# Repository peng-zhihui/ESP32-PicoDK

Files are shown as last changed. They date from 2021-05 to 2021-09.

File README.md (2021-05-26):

# 基于ESP32-PicoD4的开源迷你开发板
最近芯片疯狂涨价，ST系列的MCU价格已经上天，所以后面打算以ESP32为项目的主力平台。

> 实际上ESP32性能比STM32还强不少：
>
> * 双核架构，主频还高
> * 带WiFi/蓝牙能力（SiP封装内带射频匹配电路）
> * 原生基于FreeRTOS
> * 直接兼容Arduino生态
> * GPIO-Matrix（神器，GPIO互换，PCB Layout友好度拉满）
> * 接口丰富（3个UART、2个I2C、2个SPI、**居然还带CAN**）
> * SiP封装，外围电路极其简洁

最重要的，在芯片价格涨麻了的今天，ESP32只要十多元一片，好家伙我直接推爆好吗。

同时为了方便以后做原型验证，需要用有一个评估板，看了一圈市面上并没有很满意的（连TypeC的都没几个），所以花了一下午自己设计了一个，也开源给大家。

**板子设计已打样验证无误，好用记得点星星**👇

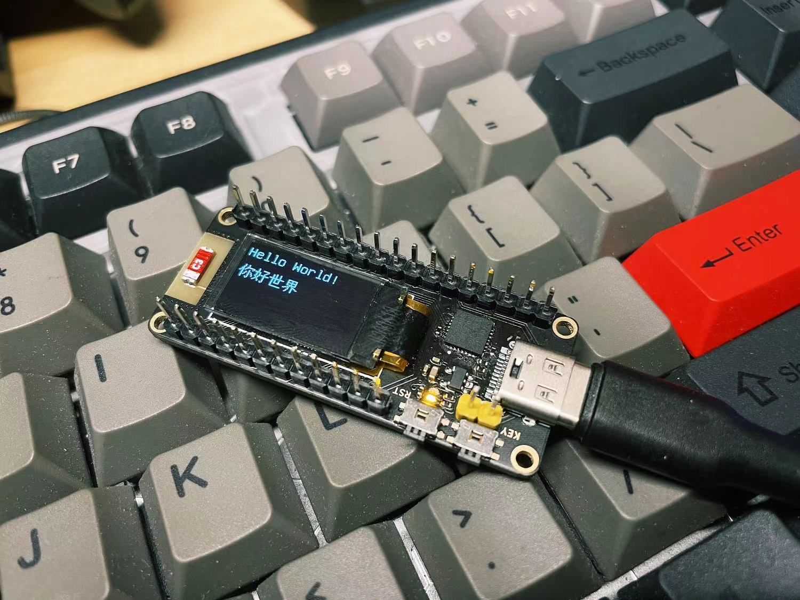
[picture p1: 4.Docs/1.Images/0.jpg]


##  特性

* 所有GPIO引出
* 板载一个MPU6050、一个OLED、一个CAN-PHY芯片、一个USB转串口、一个用户LED、一个用户按键
* 上面提到的外设芯片都是可以在板子背面通过**跳线**选择连接GPIO或者断开的，所以不影响GPIO作其他用途
* 极致迷你尺寸
* 带配套亚克力外壳（设计中稍后更新）

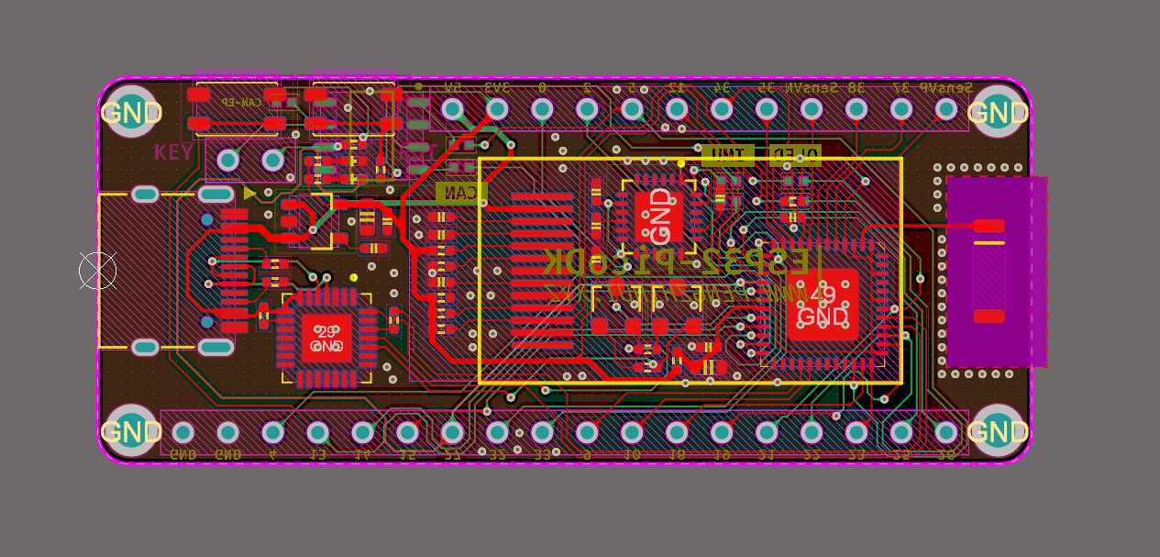
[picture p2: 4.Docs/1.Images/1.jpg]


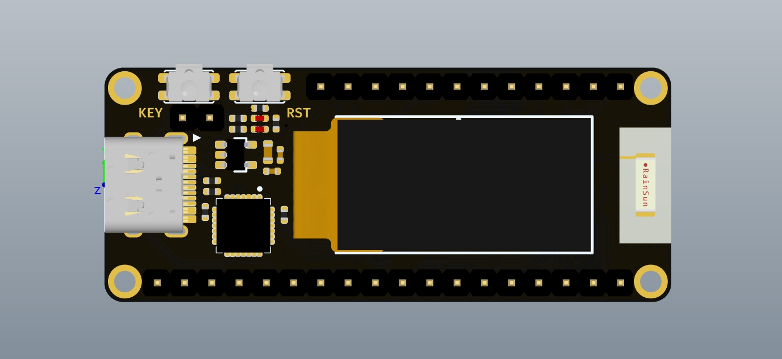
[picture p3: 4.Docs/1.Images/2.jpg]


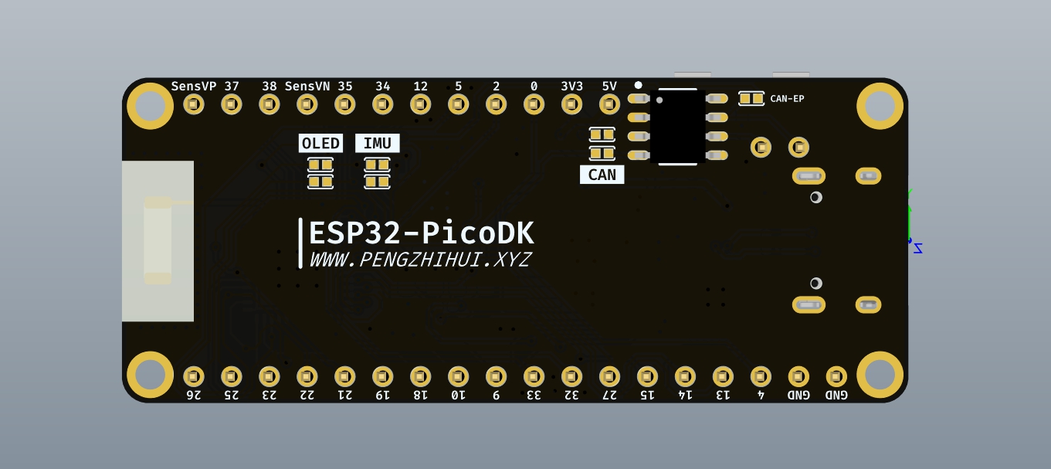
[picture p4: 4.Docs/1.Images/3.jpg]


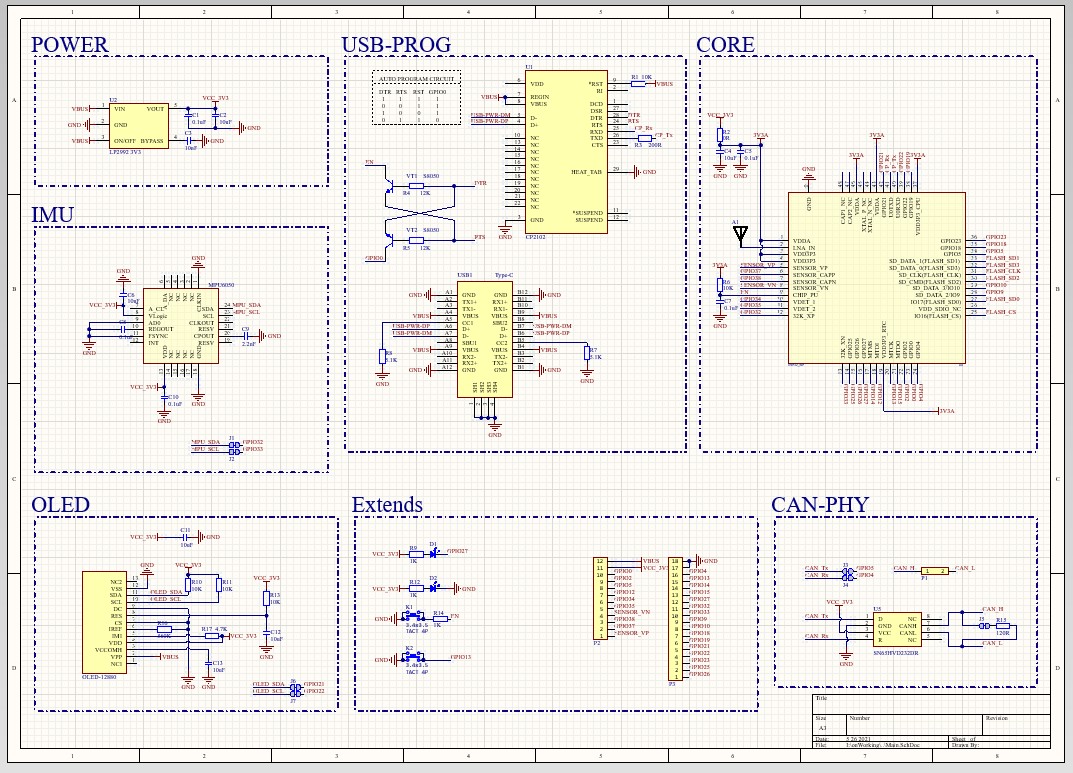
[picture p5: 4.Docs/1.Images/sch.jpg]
sch


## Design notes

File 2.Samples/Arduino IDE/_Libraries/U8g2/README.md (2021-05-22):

# U8g2_Arduino: Arduino Monochrome Graphics Library

https://raw.githubusercontent.com/wiki/olikraus/u8g2/img/uc1701_dogs102_uno_board_320.jpg 

U8glib V2 library for Arduino

Description: https://github.com/olikraus/u8g2/wiki

Issue Tracker: https://github.com/olikraus/u8g2/issues

Download (2.25.10): https://github.com/olikraus/U8g2_Arduino/archive/master.zip

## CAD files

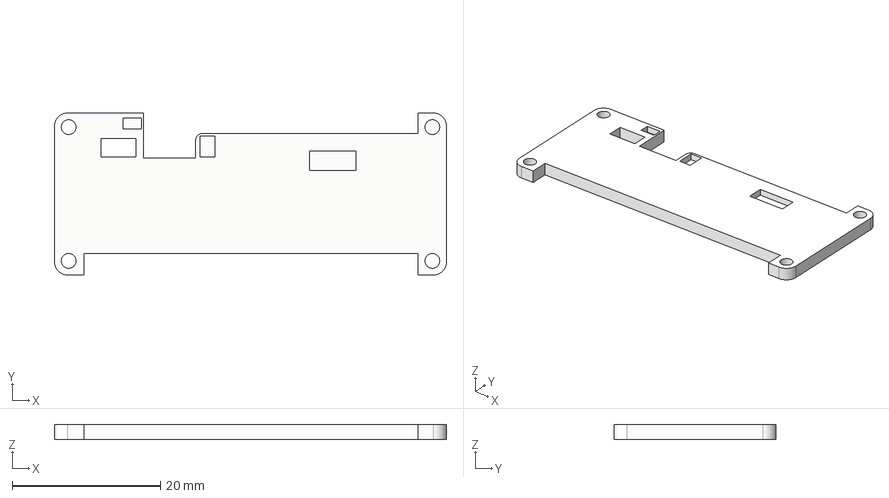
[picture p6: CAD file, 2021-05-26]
3.Case/lower.step
52.8 x 21.8 x 2.00 mm

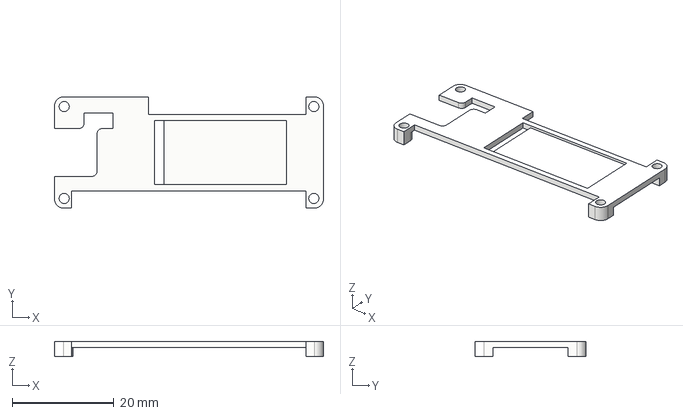
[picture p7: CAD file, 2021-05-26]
3.Case/upper.step
52.8 x 21.8 x 3.00 mm

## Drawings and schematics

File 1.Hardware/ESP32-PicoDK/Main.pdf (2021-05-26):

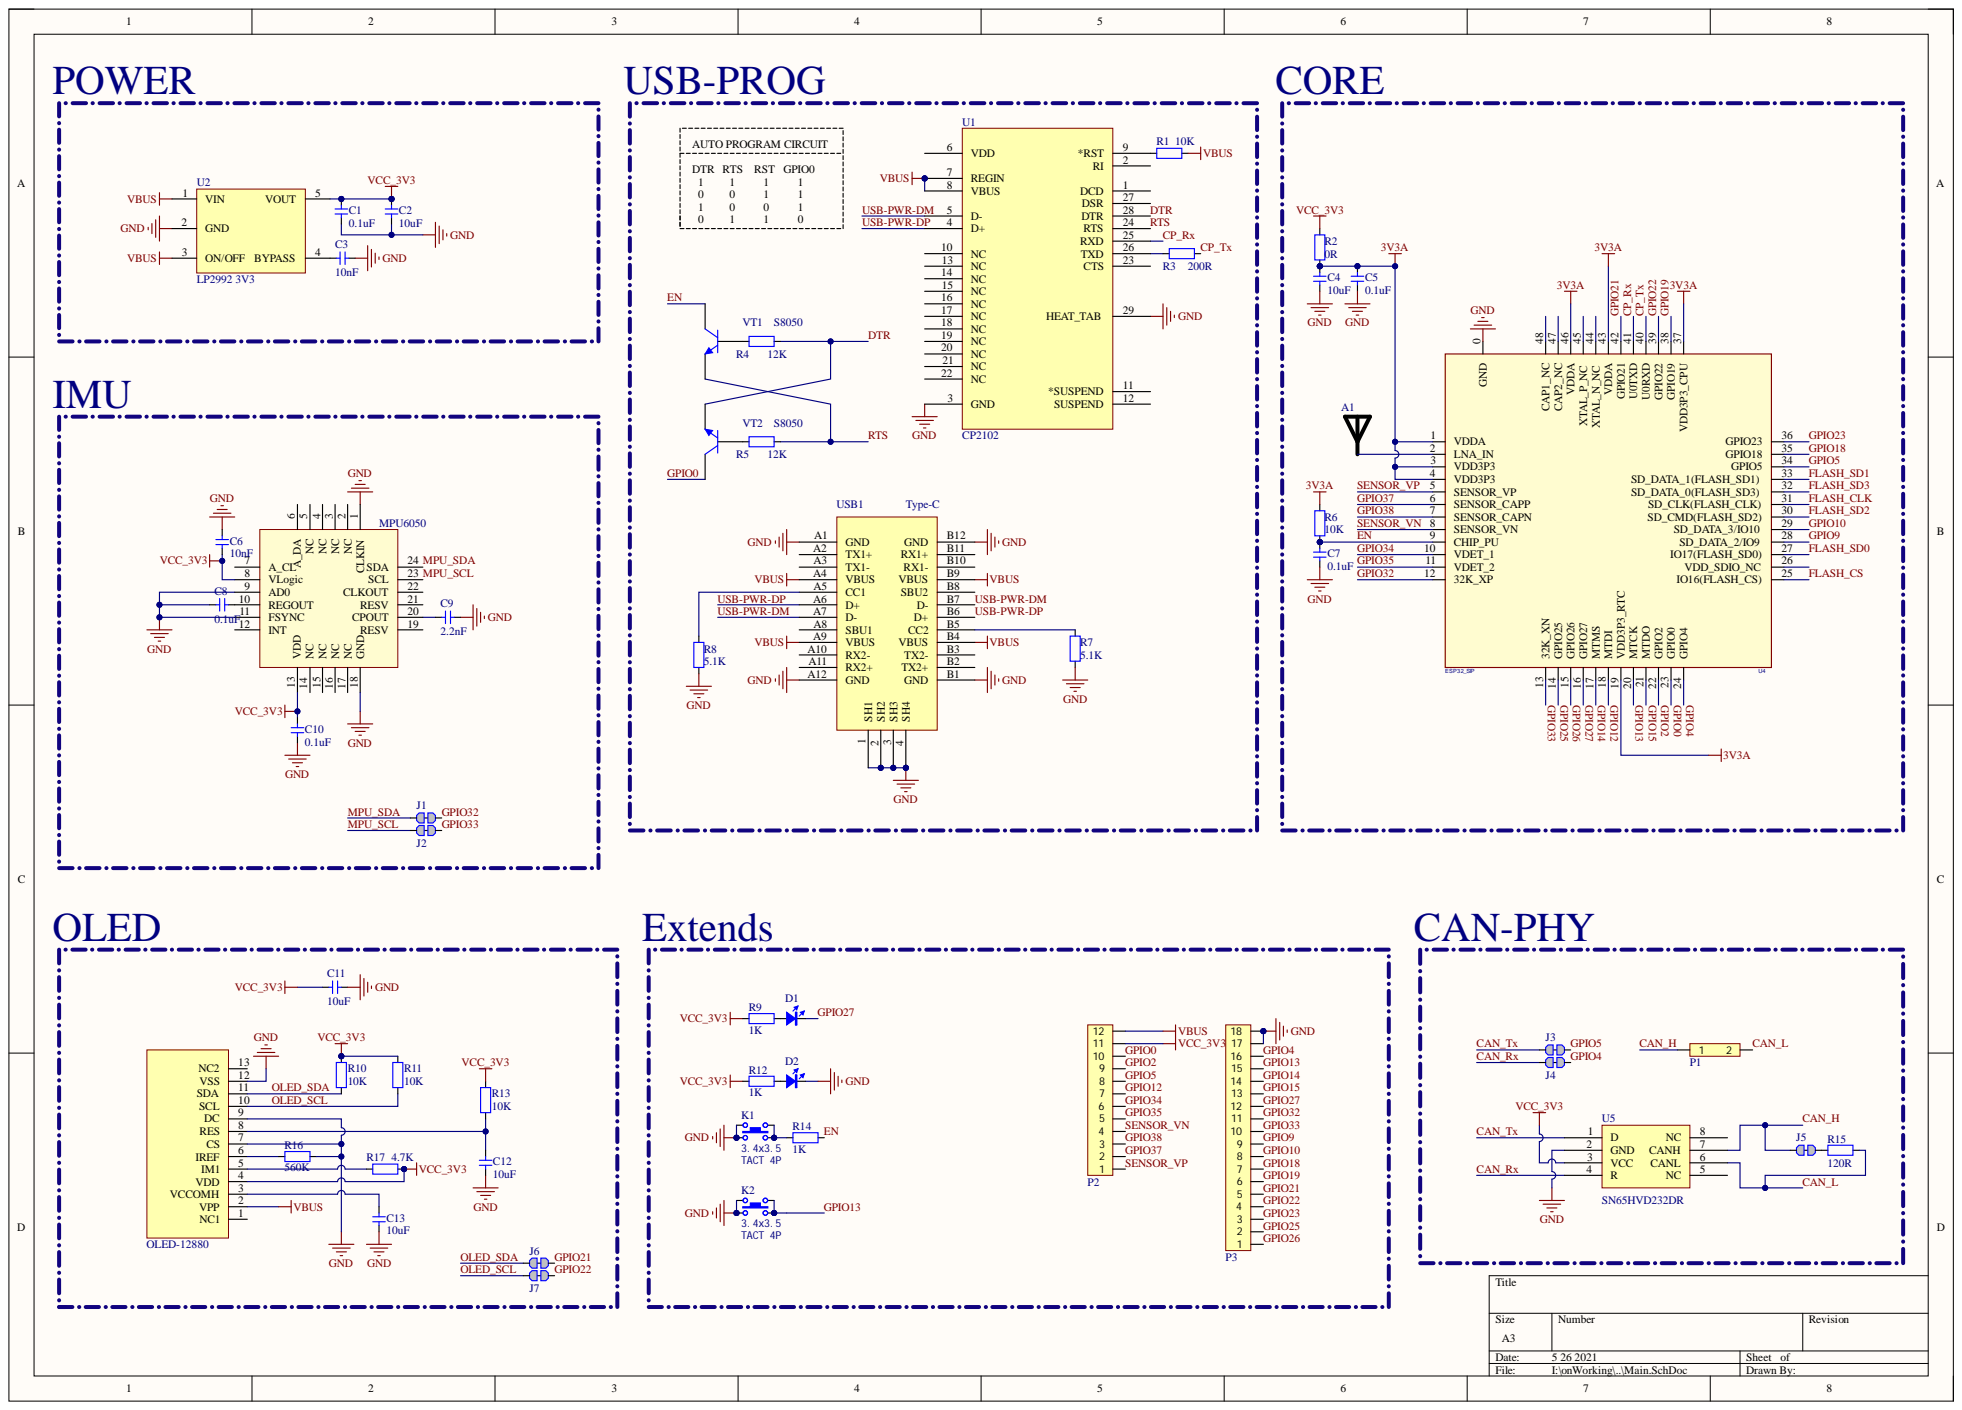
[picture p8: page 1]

CLKIN 1 NC 2 NC 3 NC 4 NC 5 A_DA 6

GND 18 RESV 19 CPOUT 20 RESV 21 CLKOUT 22 SCL 23 SDA 24

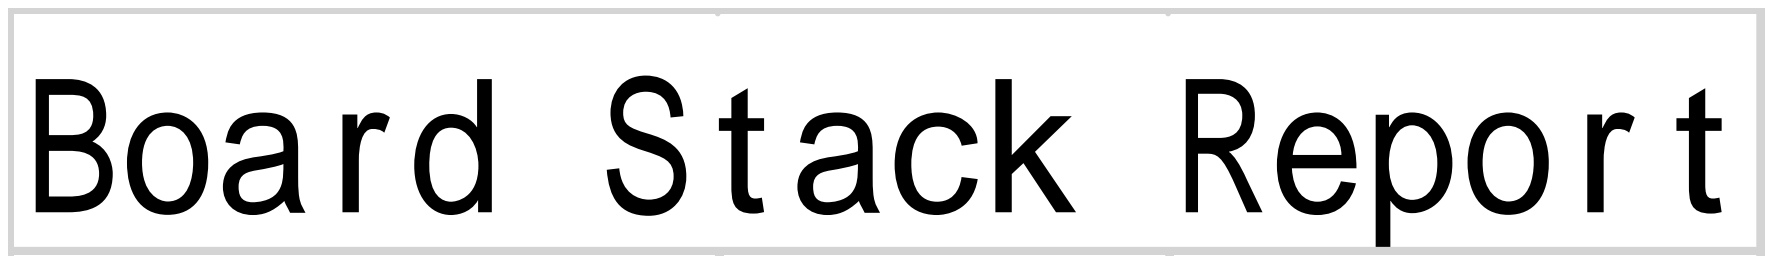
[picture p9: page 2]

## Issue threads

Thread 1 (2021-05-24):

天线部分不做阻抗匹配的话，不知道wifi性能影响大吗

Ncerzzk, 2021-05-24:
rt

peng-zhihui, 2021-05-24:
pico d4的sip封装内是带射频匹配电路的，以前的仓库里已经说明过了

发自我的iPhone

------------------ 原始邮件 ------------------
发件人: Ncerzzk ***@***.***&gt;
发送时间: 2021年5月24日 16:32
收件人: peng-zhihui/ESP32-PicoDK ***@***.***&gt;
抄送: Subscribed ***@***.***&gt;
主题: 回复：[peng-zhihui/ESP32-PicoDK] 天线部分不做阻抗匹配的话，不知道wifi性能影响大吗 (#1)

rt

—
You are receiving this because you are subscribed to this thread.
Reply to this email directly, view it on GitHub, or unsubscribe.

Ncerzzk, 2021-05-25:
原来如此，谢谢回复

Closed 2021-05-25.

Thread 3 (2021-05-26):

好意外，天线就直接引出了？LC匹配？？？

xmz0916, 2021-05-26:

peng-zhihui, 2021-05-26:
![Uploading 6766A4FE-D0EF-456A-BED3-10B2594B28B1.jpeg…]()

xmz0916, 2021-06-03:
好意外，图片也打不开，傻愣着...哈哈

xingrz, 2021-06-22:
@xmz0916 之前 HoloCube 有过相关讨论：https://github.com/peng-zhihui/HoloCubic/issues/2

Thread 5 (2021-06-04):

关于CC1/CC2 5.1K下拉电阻

fan-ziqi, 2021-06-04:
HoloCubic的TYPE-C没有下拉电阻也能正常工作，请问这个板子添加了这个电阻有什么作用啊

peng-zhihui, 2021-06-07:
用于匹配c to c的数据线，使得pd充电器输出5v

发自我的iPhone

------------------ 原始邮件 ------------------
发件人: 范子琦 ***@***.***&gt;
发送时间: 2021年6月4日 10:23
收件人: peng-zhihui/ESP32-PicoDK ***@***.***&gt;
抄送: Subscribed ***@***.***&gt;
主题: 回复：[peng-zhihui/ESP32-PicoDK] 关于CC1/CC2 5.1K下拉电阻 (#5)

HoloCubic的TYPE-C没有下拉电阻也能正常工作，请问这个板子添加了这个电阻有什么作用啊

—
You are receiving this because you are subscribed to this thread.
Reply to this email directly, view it on GitHub, or unsubscribe.

fan-ziqi, 2021-06-07:
多谢！

---原始邮件---
发件人: ***@***.***&gt;
发送时间: 2021年6月7日 12:09:35
收件人: ***@***.***&gt;;
抄送: ***@***.******@***.***&gt;;
主题: Re: [peng-zhihui/ESP32-PicoDK] 关于CC1/CC2 5.1K下拉电阻 (#5)

 用于匹配c to c的数据线，使得pd充电器输出5v

 发自我的iPhone

 ------------------ 原始邮件 ------------------
 发件人: 范子琦 ***@***.***&amp;gt;
 发送时间: 2021年6月4日 10:23
 收件人: peng-zhihui/ESP32-PicoDK ***@***.***&amp;gt;
 抄送: Subscribed ***@***.***&amp;gt;
 主题: 回复：[peng-zhihui/ESP32-PicoDK] 关于CC1/CC2 5.1K下拉电阻 (#5)

 HoloCubic的TYPE-C没有下拉电阻也能正常工作，请问这个板子添加了这个电阻有什么作用啊

 —
 You are receiving this because you are subscribed to this thread.
 Reply to this email directly, view it on GitHub, or unsubscribe.
&mdash;
You are receiving this because you authored the thread.
Reply to this email directly, view it on GitHub, or unsubscribe.

Closed 2021-07-27.

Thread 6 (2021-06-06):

想一起研究ESP32开发板的一起加群交流呀~

fan-ziqi, 2021-06-06:
点击链接加入群聊【稚晖君ESP32开发板交流】：https://jq.qq.com/?_wv=1027&k=POwHnpix
也可搜索群号码进入：682726628
大家一起进来玩呀

uint8-t, 2021-08-23:
请问大家，元器件没有丝印，不看PCB的话，大家是怎么焊接的？

fan-ziqi, 2021-08-23:
看ad的工程源文件

---原始邮件---
发件人: ***@***.***&gt;
发送时间: 2021年8月23日 16:31:53
收件人: ***@***.***&gt;;
抄送: ***@***.******@***.***&gt;;
主题: Re: [peng-zhihui/ESP32-PicoDK] 想一起研究ESP32开发板的加群交流呀~ (#6)

请问大家，元器件没有丝印，不看PCB的话，大家是怎么焊接的？

—
You are receiving this because you authored the thread.
Reply to this email directly, view it on GitHub, or unsubscribe.

peng-zhihui, 2021-08-23:
我画的元件库都是有标识的，pcb切换到3d模式，鼠标放在元器件上左上角就会显示参数了

发自我的iPhone

------------------ 原始邮件 ------------------
发件人: uint8_t ***@***.***&gt;
发送时间: 2021年8月23日 17:09
收件人: peng-zhihui/ESP32-PicoDK ***@***.***&gt;
抄送: Subscribed ***@***.***&gt;
主题: 回复：[peng-zhihui/ESP32-PicoDK] 想一起研究ESP32开发板的加群交流呀~ (#6)

就是只能在PCB里面把丝印放出来再对照着焊接么？

—
You are receiving this because you are subscribed to this thread.
Reply to this email directly, view it on GitHub, or unsubscribe.
Triage notifications on the go with GitHub Mobile for iOS or Android.

uint8-t, 2021-08-23:
噢噢噢噢，原来还可以这样，谢谢大佬

WeiXuG, 2021-09-13:
可以考虑搞一个 ESP32-D2WD的开发版吗？Pico D4性能还是弱了啊

jnxyatmjx, 2021-11-16:
请教下大神，如果现在想单片机硬件入门应该从哪里入手比较好

fan-ziqi, 2021-11-16:
51-&gt;arduino(可跳过)-&gt;stm32-&gt;其他

---原始邮件---
发件人: ***@***.***&gt;
发送时间: 2021年11月16日 14:33:02
收件人: ***@***.***&gt;;
抄送: ***@***.******@***.***&gt;;
主题: Re: [peng-zhihui/ESP32-PicoDK] 想一起研究ESP32开发板的加群交流呀~ (#6)

请教下大神，如果现在想单片机硬件入门应该从哪里入手比较好

—
You are receiving this because you authored the thread.
Reply to this email directly, view it on GitHub, or unsubscribe.

LEDZB, 2022-02-19:
大神想请教一下，为何在移植您的封装的时候，会出现以下问题呢？
Class Document Source Message Time Date No.

rao-jiechang, 2022-03-17:
好像要稚晖君的AD封装库

BillCai06, 2022-04-30:
Adafruit 有用ESP32-S2(单核) 的小开发板 带一个TFT，他们主推I2C 连一切，不过还挺好玩的
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

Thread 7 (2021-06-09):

关于2.Samples中CLion工程头文件找不到的问题

uxfion, 2021-06-09:
示例程序中PlatformIO中的CLion工程，无法找到头文件
```
#include <Arduino.h>
#include <U8g2lib.h>
#include <Wire.h>
```
如果自己新建esp32工程是能找到头文件的，但是在示例中无法找到
编译报错信息为
```
ESP32-PicoDK/2.Samples/PlatformIO/ESP32-OLED/lib/SimpleCLI/src/c/arg.c:7:20: fatal error: c/arg.h: No such file or directory
compilation terminated.
ESP32-PicoDK/2.Samples/PlatformIO/ESP32-OLED/lib/SimpleCLI/src/c/cmd.c:10:37: fatal error: c/comparator.h: No such file or directory
compilation terminated.
```
初步认为是SimpleCLI的问题（自己在此工程中是没有配置和使用过SimpleCLI的），希望大佬能给指明下处理这个问题的方向 @peng-zhihui

peng-zhihui, 2021-06-09:
cmakelist里删掉这个库的引用就行了，这是我忘了删了

发自我的iPhone

------------------ 原始邮件 ------------------
发件人: FION ***@***.***&gt;
发送时间: 2021年6月9日 23:57
收件人: peng-zhihui/ESP32-PicoDK ***@***.***&gt;
抄送: 稚晖 ***@***.***&gt;, Mention ***@***.***&gt;
主题: 回复：[peng-zhihui/ESP32-PicoDK] 关于2.Samples中CLion工程头文件找不到的问题 (#7)

示例程序中PlatformIO中的CLion工程，无法找到头文件
 #include <Arduino.h&gt; #include <U8g2lib.h&gt; #include <Wire.h&gt;
如果自己新建esp32工程是能找到头文件的，但是在示例中无法找到
 编译报错信息为
 ESP32-PicoDK/2.Samples/PlatformIO/ESP32-OLED/lib/SimpleCLI/src/c/arg.c:7:20: fatal error: c/arg.h: No such file or directory compilation terminated. ESP32-PicoDK/2.Samples/PlatformIO/ESP32-OLED/lib/SimpleCLI/src/c/cmd.c:10:37: fatal error: c/comparator.h: No such file or directory compilation terminated.
初步认为是SimpleCLI的问题（自己在此工程中是没有配置和使用过SimpleCLI的），希望大佬能给指明下处理这个问题的方向 @peng-zhihui

—
You are receiving this because you were mentioned.
Reply to this email directly, view it on GitHub, or unsubscribe.

Closed 2021-06-13.

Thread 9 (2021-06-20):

关于MPU无法正常读取的问题

EListenX, 2021-06-20:
板载MPU无法正常工作，去掉跳线电阻，外挂模块模块可以正常工作，焊接在板子上就不行，只有在上电的一瞬间可以读取一个固定值，按下reset键，显示初始化失败，外挂模块则可以正常初始化，正常读取mpu的状态信息

peng-zhihui, 2021-06-20:
检查焊接，或者买到假芯片了，我之前买过200多片坏的。

发自我的iPhone

------------------ 原始邮件 ------------------
发件人: EListen ***@***.***&gt;
发送时间: 2021年6月20日 15:36
收件人: peng-zhihui/ESP32-PicoDK ***@***.***&gt;
抄送: Subscribed ***@***.***&gt;
主题: 回复：[peng-zhihui/ESP32-PicoDK] 关于MPU无法正常读取的问题 (#9)

EListenX, 2021-06-25:
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
我想应该是电路问题 按照原理图几个引脚没有接地 新的issue也是反映的这个问题

peng-zhihui, 2021-06-25:
那几个引脚不影响，已经好多人做好了没问题

发自我的iPhone

------------------ 原始邮件 ------------------
发件人: EListen ***@***.***&gt;
发送时间: 2021年6月25日 19:30
收件人: peng-zhihui/ESP32-PicoDK ***@***.***&gt;
抄送: 稚晖 ***@***.***&gt;, Comment ***@***.***&gt;
主题: 回复：[peng-zhihui/ESP32-PicoDK] 关于MPU无法正常读取的问题 (#9)

Closed 2021-07-27.

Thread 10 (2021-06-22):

MPU的AD0和FSYNC引脚未接地

gleefish, 2021-06-22:
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
我试了几个MPU芯片读出来的地址都是0x69，然后数据只传输一组后保持不变。AD0接地的话，地址应该是0x68，不知道是否是AD0的影响，我买了MPU模块正在路上，准备排查一下是否是mpu故障还是AD0悬空导致的问题，大家有遇到类似问题嘛？谢谢

gleefish, 2021-07-06:
查看pcb文件发现两个引脚未接地，修改后mpu正常工作，设备iic地址也正常显示为0x68，供大家参考。

stig3, 2021-07-22:
同样的问题，数据只传输一组后保持不变，看到PCB上fsync那块是死铜，然后飞了跟线，让fsync接地，ad0悬空不影响，地址设置成0x69, 然后就工作正常了。
看了一下datasheet, 这个是同步信号，工作模式应该是收到低电平再更新数据
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
如果悬空的话，那就不更新数据的，所以这个数据只传输一组后保持不变的问题应该就是fsync悬空导致的。

peng-zhihui, 2021-07-22:
新版已经加上了。

------------------&nbsp;原始邮件&nbsp;------------------
发件人:                                                                                                                        "peng-zhihui/ESP32-PicoDK"                                                                                    ***@***.***&gt;;
发送时间:&nbsp;2021年7月22日(星期四) 上午10:54
***@***.***&gt;;
***@***.***&gt;;
主题:&nbsp;Re: [peng-zhihui/ESP32-PicoDK] MPU的AD0和FSYNC引脚未接地 (#10)

同样的问题，数据只传输一组后保持不变，看到PCB上fsync那块是死铜，然后飞了跟线，让fsync接地，ad0悬空不影响，地址设置成0x69, 然后就工作正常了。
 看了一下datasheet, 这个是同步信号，工作模式应该是收到低电平再更新数据

 如果悬空的话，那就不更新数据的，所以这个数据只传输一组后保持不变的问题应该就是fsync悬空导致的。

—
You are receiving this because you are subscribed to this thread.
Reply to this email directly, view it on GitHub, or unsubscribe.

Closed 2021-07-27.

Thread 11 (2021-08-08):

第一次烧录的后续烧录失败

nanshenwei, 2021-08-08:
焊接好IMU CP2102 ESP32以及必须的外围电路和烧录电路后，可以轻松成功烧录IMU例程，并成功运行程序，没有异常正常输出IMU信息。但是紧接着烧录第二次的时候（没有任何其他动作）会一直不能自动进入下载模式
尝试重新焊接  更换复位电路的0.1uF电容为1uF以及更换三极管12k电阻至1k都不能成功。更换新的ESP32芯片后仍然只能自动烧录第一次。

同时，无法通过复位按键复位（除非把复位按键的1k电阻换成0Ohm电阻），不知道是否有其他原因造成。

使用Arduino IDE进行的烧录

nanshenwei, 2021-08-08:
只能通过烧录时手动短接IO0和GND进入下载模式

nanshenwei, 2021-08-08:
1. 示波器看如果按照高电平为0.75*VDD的话理论上是没问题的，但不知道为什么芯片还是不认为EN上升沿的时候IO0是低电平。
2. 尝试把EN引脚电容0.1uF换成2.2uF（换成1uF之后结果为1.所描述的）就能自动下载了。
3. esptool.py这个脚本中升高EN的时候不延时等待IO0变为低电平，导致EN上升沿的过程中 ，IO0会有个矩形波（示波器显示的矩形波可能是这样产生的？）但是更改脚本无效，Arduino IDE应该是使用封装好的EXE文件运行的脚本，所以直接改脚本无效。

uxfion, 2022-03-16:
按楼主的尝试把EN引脚电容0.1uF换成2.2uF，可以自动下载

Closed 2021-08-08.

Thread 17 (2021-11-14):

A fatal error occurred: MD5 of file does not match data in flash!

NPcc-c, 2021-11-14:
烧写的时候需要按着key要不然连接不成功。然后后面又出现了这个问题
A fatal error occurred: MD5 of file does not match data in flash!、
这个问题该怎么解决？

NPcc-c, 2021-11-16:
解决了，感谢稚晖鸽在知乎上回答我的问题。R14换成200R，C7换成1uF就可以了

GreenShadeZhang, 2023-05-15:
> 解决了，感谢稚晖鸽在知乎上回答我的问题。R14换成200R，C7换成1uF就可以了

你能给我一些关于这个火星车同样问题的一些建议吗？我现在复刻火星车也遇到了同样的问题，我看两者的电路很相似。
https://github.com/peng-zhihui/MiniRover-Hardware/issues/13

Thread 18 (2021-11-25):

rst:0x7 (TG0WDT_SYS_RESET),boot:0x13 (SPI_FAST_FLASH_BOOT) flash read err, 1000

zhendehanzi, 2021-11-25:
rst:0x7 (TG0WDT_SYS_RESET),boot:0x13 (SPI_FAST_FLASH_BOOT)
flash read err, 1000
ets_main.c 371
ets Jun  8 2016 00:22:57
这个问题困扰好久了，不知道怎么解决
查询了下，说需要MTDI引脚以某种方式拉低，但似乎没有作用

zhendehanzi, 2021-11-29:
解决了，供电问题

Closed 2021-11-29.

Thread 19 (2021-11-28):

没有找到PCB文件啊

mailonghua, 2021-11-28:
请教一下，PCB文件在仓库中没有看到，这个是没开出来吗

JiaoLu-JNU, 2021-11-29:
不就在那吗

mailonghua, 2021-11-29:
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
在哪里，从commit回退了一笔提交后，看到了pcb

JiaoLu-JNU, 2021-11-29:
好像还真是

peng-zhihui, 2021-11-29:
之前的提交错误，已修复

wc7086, 2022-04-24:
> 之前的提交错误，已修复

并没有修复

peng-zhihui, 2022-04-24:
再看看

Closed 2021-11-29.

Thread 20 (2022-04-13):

尝试复现，并遇到问题，想请教下稚晖君及各位大佬

mmdjiji, 2022-04-13:
关于我的复现过程记录描述在这里：https://www.yuque.com/docs/share/f979c460-2324-497b-8bbf-e2ea19f214f1

目前：
- 供电正常，分别量了5V和3.3V
- CP2102识别了
- ESP32-PICO-D4没有识别
- GPIO0的电压为2.17V
- GPIO2的电压为1.06V

peng-zhihui, 2022-04-13:
检查焊接，同时可以参考这个https://github.com/peng-zhihui/ESP32-PicoDK/issues/11

mmdjiji, 2022-04-18:
复现成功了，感谢稚晖君，我换了张PICO按相同工艺焊接就ok了，所以怀疑是PICO因为未知原因损坏了。

效果如下：

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

但是这个是我在关了全屋灯光之后照的，所以显示屏亮度过低，关于这个我怀疑是显示屏质量问题，打算再买一个显示屏换掉试试。

peng-zhihui, 2022-04-18:
屏幕的电压检查一下，3.3V和5V是否正常

mmdjiji, 2022-04-18:
检查了，3.3V和5V都是正常的

mmdjiji, 2022-04-21:
后来换了个屏幕成功了，可见是屏幕质量问题。。。

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

Closed 2022-04-18.

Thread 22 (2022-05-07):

ESP32-OLED的头文件问题

SkrShadow, 2022-05-07:
大佬好，ESP32-OLED的main.cpp中，第三行引用的U8g2lib.h没有出现在lib/U8g2/src/中，我在VSCode中使用pio对其进行编译的时候会提示找不到头文件。
（看到了.idea，没有在CLion下使用过pio，不知道在CLion下是否需要这个文件）

Lance0724, 2022-06-23:
不知道大佬为什么删除了这个文件U8g2lib.h
不知道是不是因为lic问题

Drswith, 2022-09-04:
要用SH1107的宏

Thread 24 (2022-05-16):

OLED屏幕选型问题

CodeChenL, 2022-05-16:
你好，野生钢铁侠！）
`U8G2_SSD1306_128X80_NONAME_F_HW_I2C`这款屏幕我找了好久都找不到，
请问[https://item.taobao.com/item.htm?spm=a1z09.2.0.0.7eeb2e8dznyLsM&id=665034068875&_u=h2073k18bn28ea](url)这款屏幕可以吗，据我了解sh1107也支持i2c？
这是[https://item.taobao.com/item.htm?spm=a1z09.2.0.0.7eeb2e8dznyLsM&id=665034068875&_u=h2073k18bn28ea](url)的参数和引脚定义：
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

song-hailong, 2022-05-27:
我用的这家
https://item.taobao.com/item.htm?spm=a1z09.2.0.0.3ef32e8dzDaUtp&id=596799616504&_u=r1vdumg491ae

CodeChenL, 2022-05-27:
> 我用的这家 https://item.taobao.com/item.htm?spm=a1z09.2.0.0.3ef32e8dzDaUtp&id=596799616504&_u=r1vdumg491ae

谢谢，我看了下和我发的淘宝链接是同一个模组，但是我用库里的例程跑的时候，并没有反应，但是i2c有通讯上（

song-hailong, 2022-05-27:
> > 我用的这家https://item.taobao.com/item.htm?spm=a1z09.2.0.0.3ef32e8dzDaUtp&id=596799616504&_u=r1vdumg491ae
>
> 谢谢，我下和我发的淘宝链接是同一个模组，但是我用库里的例程跑的时候，并没有反应，i2c有通讯上的相关信息（

更新一下U8g2库就行
https://github.com/olikraus/U8g2_Arduino/releases

CodeChenL, 2022-05-27:
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

谢谢，有空我会试试

Pan348, 2022-08-30:
可以试试  U8G2_SH1107_128X80_F_HW_I2C 函数，我用了以后就正常了

CodeChenL, 2022-08-30:
> 可以试试 U8G2_SH1107_128X80_F_HW_I2C 函数，我用了以后就正常了

试过了，没用（

Pan348, 2022-08-30:
> > 可以试试 U8G2_SH1107_128X80_F_HW_I2C 函数，我用了以后就正常了
>
> 试过了，没用（

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

Pan348, 2022-08-30:
> > 可以试试 U8G2_SH1107_128X80_F_HW_I2C 函数，我用了以后就正常了
>
> 试过了，没用（

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

我是这样用的

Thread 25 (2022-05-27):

MPU6050初始化失败

song-hailong, 2022-05-27:
有遇到程序卡在accelgyro.initialize();的吗？串口只打印了下面的信息，就卡死了。
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

hanchuangqj, 2022-06-01:
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

CodeChenL, 2022-06-10:
这个问题我也遇到了，可以找到`Wrie.h`这个文件，在开头添加`#define CONFIG_DISABLE_HAL_LOCKS true`宏定义就行了

Drswith, 2022-09-04:
是电路设计问题，
问题一：电路图控制I2C地址的AD0引脚虽然接地了但是没有加下拉电阻，导致电压浮空，使用0x69地址可解决，但是也不稳定，终极办法就是AD0飞线个10k下拉电阻到GND
问题二：MPU的I2C没有接上拉电阻，容易被信号干扰，解决办法一样是SCL、SDA分别飞线4.7K电阻到VCC

oYuXo, 2022-09-16:
对比ad源文件发现Gerber文件中mpu6050 9、10、11引脚侧的地孔缺失了，直接用Gerber文件打板出来，会导致AD0浮空，我怀疑是这个原因导致初始化失败的
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

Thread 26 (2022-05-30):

关于 A1 处陶瓷天线的型号问题

TPAXcc, 2022-05-30:
稚晖君，你在 A1 处的型号标识是不是弄错了啊，我在 [Rainsun 官网](www.rainsun.com/2-4ghz-5ghzwifi-蓝牙-zigbee天线系列/)也没找到 AN5120 啊，是不是 AN2051?

TPAXcc, 2022-06-02:
@donjion 没事，反正就就几块板🙃

TPAXcc, 2022-06-02:
@donjion 没事，反正就就几块板🙃

TPAXcc, 2022-06-02:
@donjion 实在不行也可以自己用铺铜做天线嘛(

Closed 2023-01-22.

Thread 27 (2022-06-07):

arduino U8g2lib 报错

ka2223, 2022-06-07:
项目库文件夹里的 U8g2 放在C盘 Documents\Arduino\libraries ，也试过打包成ZIp在软件里添加，都是不行啊。
提示这个C:\Users\Jhin\Documents\Arduino\ESP32-OLED\ESP32-OLED.ino:3:21: fatal error: U8g2lib.h: No such file or directory

hanchuangqj, 2022-06-07:
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
下载最新U8G2库

ka2223, 2022-06-07:
> 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 下载最新U8G2库

下载了 还是报错哎 ，大神救救孩子吧

hanchuangqj, 2022-06-07:
还得改下函数，之前那个是12864分辨率的呀，在最新库里可以找到sh1107的12880驱动

---原始邮件---
发件人: ***@***.***&gt;
发送时间: 2022年6月7日(周二) 下午3:53
收件人: ***@***.***&gt;;
抄送: ***@***.******@***.***&gt;;
主题: Re: [peng-zhihui/ESP32-PicoDK] arduino U8g2lib 报错 (Issue #27)

 下载最新U8G2库

下载了 还是报错哎 ，大神救救孩子吧

—
Reply to this email directly, view it on GitHub, or unsubscribe.
You are receiving this because you commented.Message ID: ***@***.***&gt;

ka2223, 2022-06-07:
> 还得改下函数，之前那个是12864分辨率的呀，在最新库里可以找到sh1107的12880驱动
> […](#)
> ---原始邮件--- 发件人: ***@***.***&gt; 发送时间: 2022年6月7日(周二) 下午3:53 收件人: ***@***.***&gt;; 抄送: ***@***.******@***.***&gt;; 主题: Re: [peng-zhihui/ESP32-PicoDK] arduino U8g2lib 报错 (Issue #27) 下载最新U8G2库 下载了 还是报错哎 ，大神救救孩子吧 — Reply to this email directly, view it on GitHub, or unsubscribe. You are receiving this because you commented.Message ID: ***@***.***&gt;

原来如此啊，感谢感谢O(∩_∩)O

ka2223, 2022-06-07:
已解决

Closed 2022-06-07.

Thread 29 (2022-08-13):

关于OLED屏幕VPP引脚电压过低的问题

Takato20, 2022-08-13:
稚晖君您好，感谢您带来的一个个优秀的作品。
在最近复刻PicoDK的过程中，发现屏幕亮度较暗，难以看清内容。起初以为是焊接问题，排查后查阅了屏幕的数据手册，发现该**屏幕VPP引脚供电电压应为9V**，而在您的作品中是由VBUS直接供电，在大多数以TypeC供电的场景下，无法达到9V的要求，因此会影响显示效果。
同时，电源指示灯D1亮度似乎也有所偏高，导致在高亮LED下屏幕更加不易看清。
因此个人认为能否为屏幕驱动单独添加一个小型升压电路以满足屏幕驱动要求，同时增大LED串联电阻阻值从而减小亮度，可能会有更好的显示效果。
以上是我个人在学习过程中的一点想法，以供您参考，谢谢。

peng-zhihui, 2022-08-14:
OLED 5V的亮度我觉得正好的，所以没加升压，你可以自己调整一下哈。

Takato20, 2022-08-14:
> OLED 5V的亮度我觉得正好的，所以没加升压，你可以自己调整一下哈。

好的。之前也有和许多遇到相同情况的小伙伴讨论过。看到这里没人提就来请教了一下。这里附上规格书里这款屏幕常用的升压驱动电路，当做是给其他小伙伴的小tips吧。
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
将屏幕的VBUS转接到9V输出端。
感谢稚晖君。

Closed 2022-08-14.

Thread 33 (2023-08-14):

A fatal error occurred: MD5 of file does not match data in flash!

Shatirah, 2023-08-14:
Hi, I got this error when try to flash my code to ESP32. Does anyone know how to solve this issue?

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

Closed 2023-10-25.

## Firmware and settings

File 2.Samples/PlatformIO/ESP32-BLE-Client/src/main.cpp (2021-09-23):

#include <Arduino.h>
#include <NimBLEDevice.h>

void scanEndedCB(NimBLEScanResults results);

static NimBLEAdvertisedDevice* advDevice;

static bool doConnect = false;
static uint32_t scanTime = 0; /** 0 = scan forever */

class ClientCallbacks : public NimBLEClientCallbacks
{
    void onConnect(NimBLEClient* pClient)
    {
        Serial.println("Connected");
        /** After connection we should change the parameters if we don't need fast response times.
         *  These settings are 150ms interval, 0 latency, 450ms timout.
         *  Timeout should be a multiple of the interval, minimum is 100ms.
         *  I find a multiple of 3-5 * the interval works best for quick response/reconnect.
         *  Min interval: 120 * 1.25ms = 150, Max interval: 120 * 1.25ms = 150, 0 latency, 60 * 10ms = 600ms timeout
         */
        pClient->updateConnParams(120, 120, 0, 60);
    };

    void onDisconnect(NimBLEClient* pClient)
    {
        Serial.print(pClient->getPeerAddress().toString().c_str());
        Serial.println(" Disconnected - Starting scan");
        NimBLEDevice::getScan()->start(scanTime, scanEndedCB);
    };

    /** Called when the peripheral requests a change to the connection parameters.
     *  Return true to accept and apply them or false to reject and keep
     *  the currently used parameters. Default will return true.
     */
    bool onConnParamsUpdateRequest(NimBLEClient* pClient, const ble_gap_upd_params* params)
    {
        if (params->itvl_min < 24)
        { /** 1.25ms units */
            return false;
        } else if (params->itvl_max > 40)
        { /** 1.25ms units */
            return false;
        } else if (params->latency > 2)
        { /** Number of intervals allowed to skip */
            return false;
        } else if (params->supervision_timeout > 100)
        { /** 10ms units */
            return false;
        }

        return true;
    };

    /********************* Security handled here **********************
    ****** Note: these are the same return values as defaults ********/
    uint32_t onPassKeyRequest()
    {
        Serial.println("Client Passkey Request");
        /** return the passkey to send to the server */
        return 123456;
    };

    bool onConfirmPIN(uint32_t pass_key)
    {
        Serial.print("The passkey YES/NO number: ");
        Serial.println(pass_key);
        /** Return false if passkeys don't match. */
        return true;
    };

    /** Pairing process complete, we can check the results in ble_gap_conn_desc */
    void onAuthenticationComplete(ble_gap_conn_desc* desc)
    {
        if (!desc->sec_state.encrypted)
        {
            Serial.println("Encrypt connection failed - disconnecting");
            /** Find the client with the connection handle provided in desc */
            NimBLEDevice::getClientByID(desc->conn_handle)->disconnect();
            return;
        }
    };
};

class AdvertisedDeviceCallbacks : public NimBLEAdvertisedDeviceCallbacks
{
    void onResult(NimBLEAdvertisedDevice* advertisedDevice)
    {
        Serial.print("Advertised Device found: ");
       Serial.println(advertisedDevice->toString().c_str());
        if (advertisedDevice->isAdvertisingService(NimBLEUUID("0001")))
        // if (advertisedDevice->getAddress() == NimBLEAddress("50:02:91:ac:b0:6a"))
        {
            Serial.println("Found Dummy-Robot!");
            /** stop scan before connecting */
            NimBLEDevice::getScan()->stop();
            /** Save the device reference in a global for the client to use*/
            advDevice = advertisedDevice;
            /** Ready to connect now */
            doConnect = true;
        }
    };
};

void notifyCB(NimBLERemoteCharacteristic* pRemoteCharacteristic, uint8_t* pData, size_t length, bool isNotify)
{
    std::string str = isNotify ? "Notification" : "Indication";
    str += " from ";
    /** NimBLEAddress and NimBLEUUID have std::string operators */
    str += std::string(pRemoteCharacteristic->getRemoteService()->getClient()->getPeerAddress());
    str += ": Service = " + std::string(pRemoteCharacteristic->getRemoteService()->getUUID());
    str += ", Characteristic = " + std::string(pRemoteCharacteristic->getUUID());
    str += ", Value = ";
    Serial.print(str.c_str());
    Serial.println(pRemoteCharacteristic->getValue<float>());
}

void scanEndedCB(NimBLEScanResults results)
{
    Serial.println("Scan Ended");
}


static ClientCallbacks clientCB;

bool connectToServer()
{
    NimBLEClient* pClient = nullptr;

    /** Check if we have a client we should reuse first **/
    if (NimBLEDevice::getClientListSize())
    {
        /** Special case when we already know this device, we send false as the
         *  second argument in connect() to prevent refreshing the service database.
         *  This saves considerable time and power.
         */
        pClient = NimBLEDevice::getClientByPeerAddress(advDevice->getAddress());
        if (pClient)
        {
            if (!pClient->connect(advDevice, false))
            {
                Serial.println("Reconnect failed");
                return false;
            }
            Serial.println("Reconnected client");
        }
            /** We don't already have a client that knows this device,
             *  we will check for a client that is disconnected that we can use.
             */
        else
        {
            pClient = NimBLEDevice::getDisconnectedClient();
        }
    }

    /** No client to reuse? Create a new one. */
    if (!pClient)
    {
        if (NimBLEDevice::getClientListSize() >= NIMBLE_MAX_CONNECTIONS)
        {
            Serial.println("Max clients reached - no more connections available");
            return false;
        }

        pClient = NimBLEDevice::createClient();

        Serial.println("New client created");

        pClient->setClientCallbacks(&clientCB, false);
        /** Set initial connection parameters: These settings are 15ms interval, 0 latency, 120ms timout.
         *  These settings are safe for 3 clients to connect reliably, can go faster if you have less
         *  connections. Timeout should be a multiple of the interval, minimum is 100ms.
         *  Min interval: 12 * 1.25ms = 15, Max interval: 12 * 1.25ms = 15, 0 latency, 51 * 10ms = 510ms timeout
         */
        pClient->setConnectionParams(12, 12, 0, 51);
        /** Set how long we are willing to wait for the connection to complete (seconds), default is 30. */
        pClient->setConnectTimeout(5);


        if (!pClient->connect(advDevice))
        {
            /** Created a client but failed to connect, don't need to keep it as it has no data */
            NimBLEDevice::deleteClient(pClient);
            Serial.println("Failed to connect, deleted client");
            return false;
        }
    }

    if (!pClient->isConnected())
    {
        if (!pClient->connect(advDevice))
        {
            Serial.println("Failed to connect");
            return false;
        }
    }

    Serial.print("Connected to: ");
    Serial.println(pClient->getPeerAddress().toString().c_str());
    Serial.print("RSSI: ");
    Serial.println(pClient->getRssi());

    /** Now we can read/write/subscribe the charateristics of the services we are interested in */
    NimBLERemoteService* pSvc = nullptr;
    NimBLERemoteCharacteristic* pChr = nullptr;
    NimBLERemoteDescriptor* pDsc = nullptr;

    pSvc = pClient->getService("0001");
    if (pSvc)
    {     /** make sure it's not null */
        pChr = pSvc->getCharacteristic("1003");

        if (pChr)
        {     /** make sure it's not null */
            if (pChr->canRead())
            {
                Serial.print(pChr->getUUID().toString().c_str());
                Serial.print(" Value: ");
                Serial.println(*(float*) (pChr->readValue().c_str()));
            }

            if (pChr->canWrite())
            {
                if (pChr->writeValue("Tasty"))
                {
                    Serial.print("Wrote new value to: ");
                    Serial.println(pChr->getUUID().toString().c_str());
                } else
                {
                    /** Disconnect if write failed */
                    pClient->disconnect();
                    return false;
                }

                if (pChr->canRead())
                {
                    Serial.print("The value of: ");
                    Serial.print(pChr->getUUID().toString().c_str());
                    Serial.print(" is now: ");
                    Serial.println(pChr->readValue().c_str());
                }
            }

            /** registerForNotify() has been deprecated and replaced with subscribe() / unsubscribe().
             *  Subscribe parameter defaults are: notifications=true, notifyCallback=nullptr, response=false.
             *  Unsubscribe parameter defaults are: response=false.
             */
            if (pChr->canNotify())
            {
                //if(!pChr->registerForNotify(notifyCB)) {
                if (!pChr->subscribe(true, notifyCB))
                {
                    /** Disconnect if subscribe failed */
                    pClient->disconnect();
                    return false;
                }
            } else if (pChr->canIndicate())
            {
                /** Send false as first argument to subscribe to indications instead of notifications */
                //if(!pChr->registerForNotify(notifyCB, false)) {
                if (!pChr->subscribe(false, notifyCB))
                {
                    /** Disconnect if subscribe failed */
                    pClient->disconnect();
                    return false;
                }
            }
        }

    } else
    {
        Serial.println("0001 service not found.");
    }

    Serial.println("Done with this device!");
    return true;
}

void setup()
{
    Serial.begin(115200);
    Serial.println("Starting Peak-BLE Client");

    NimBLEDevice::init("Peak-BLE");

    NimBLEDevice::setSecurityAuth(false, false, true);
    NimBLEDevice::setPower(ESP_PWR_LVL_P9); /** +9db */

    /** create new scan */
    NimBLEScan* pScan = NimBLEDevice::getScan();
    /** create a callback that gets called when advertisers are found */
    pScan->setAdvertisedDeviceCallbacks(new AdvertisedDeviceCallbacks());
    /** Set scan interval (how often) and window (how long) in milliseconds */
    pScan->setInterval(20);
    pScan->setWindow(15);
    /** Active scan will gather scan response data from advertisers
     *  but will use more energy from both devices
     */
    pScan->setActiveScan(true);
    /** Start scanning for advertisers for the scan time specified (in seconds) 0 = forever
     *  Optional callback for when scanning stops.
     */
    pScan->start(scanTime, scanEndedCB);
}


void loop()
{
    /** Loop here until we find a device we want to connect to */
    while (!doConnect)
    {
        delay(1);
    }

    doConnect = false;

    /** Found a device we want to connect to, do it now */
    if (connectToServer())
    {
        Serial.println("Success! we should now be getting notifications, scanning for more!");
    } else
    {
        Serial.println("Failed to connect, starting scan");
        NimBLEDevice::getScan()->start(scanTime, scanEndedCB);
    }
}

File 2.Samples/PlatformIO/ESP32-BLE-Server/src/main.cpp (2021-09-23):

#include <Arduino.h>
#include <NimBLEDevice.h>


class ServerCallbacks : public NimBLEServerCallbacks
{
    void onConnect(NimBLEServer* pServer)
    {
        Serial.println("Client connected");
        Serial.println("Multi-connect support: start advertising");
        NimBLEDevice::startAdvertising();
    };
    /** Alternative onConnect() method to extract details of the connection.
     *  See: src/ble_gap.h for the details of the ble_gap_conn_desc struct.
     */
    void onConnect(NimBLEServer* pServer, ble_gap_conn_desc* desc)
    {
        Serial.print("Client address: ");
        Serial.println(NimBLEAddress(desc->peer_ota_addr).toString().c_str());
        /** We can use the connection handle here to ask for different connection parameters.
         *  Args: connection handle, min connection interval, max connection interval
         *  latency, supervision timeout.
         *  Units; Min/Max Intervals: 1.25 millisecond increments.
         *  Latency: number of intervals allowed to skip.
         *  Timeout: 10 millisecond increments, try for 5x interval time for best results.
         */
        pServer->updateConnParams(desc->conn_handle, 24, 48, 0, 60);
    };
    void onDisconnect(NimBLEServer* pServer)
    {
        Serial.println("Client disconnected - start advertising");
        NimBLEDevice::startAdvertising();
    };
    void onMTUChange(uint16_t MTU, ble_gap_conn_desc* desc)
    {
        Serial.printf("MTU updated: %u for connection ID: %u\n", MTU, desc->conn_handle);
    };

/********************* Security handled here **********************
****** Note: these are the same return values as defaults ********/
    uint32_t onPassKeyRequest()
    {
        Serial.println("Server Passkey Request");
        /** This should return a random 6 digit number for security
         *  or make your own static passkey as done here.
         */
        return 123456;
    };

    bool onConfirmPIN(uint32_t pass_key)
    {
        Serial.print("The passkey YES/NO number: ");
        Serial.println(pass_key);
        /** Return false if passkeys don't match. */
        return true;
    };

    void onAuthenticationComplete(ble_gap_conn_desc* desc)
    {
        /** Check that encryption was successful, if not we disconnect the client */
        if (!desc->sec_state.encrypted)
        {
            NimBLEDevice::getServer()->disconnect(desc->conn_handle);
            Serial.println("Encrypt connection failed - disconnecting client");
            return;
        }
        Serial.println("Starting BLE work!");
    };
};

class CharacteristicCallbacks : public NimBLECharacteristicCallbacks
{
    void onRead(NimBLECharacteristic* pCharacteristic)
    {
        Serial.print(pCharacteristic->getUUID().toString().c_str());
        Serial.print(": onRead(), value: ");
        Serial.println(*(float*) (pCharacteristic->getValue().c_str()));
    };

    void onWrite(NimBLECharacteristic* pCharacteristic)
    {
        Serial.print(pCharacteristic->getUUID().toString().c_str());
        Serial.print(": onWrite(), value: ");
        Serial.println(pCharacteristic->getValue().c_str());
    };
    /** Called before notification or indication is sent,
     *  the value can be changed here before sending if desired.
     */
    void onNotify(NimBLECharacteristic* pCharacteristic)
    {
        pCharacteristic->setValue((float) esp_random());
        Serial.println("Sending notification to clients");
    };


    /** The status returned in status is defined in NimBLECharacteristic.h.
     *  The value returned in code is the NimBLE host return code.
     */
    void onStatus(NimBLECharacteristic* pCharacteristic, Status status, int code)
    {
        String str = ("Notification/Indication status code: ");
        str += status;
        str += ", return code: ";
        str += code;
        str += ", ";
        str += NimBLEUtils::returnCodeToString(code);
        Serial.println(str);
    };

    void onSubscribe(NimBLECharacteristic* pCharacteristic, ble_gap_conn_desc* desc, uint16_t subValue)
    {
        String str = "Client ID: ";
        str += desc->conn_handle;
        str += " Address: ";
        str += std::string(NimBLEAddress(desc->peer_ota_addr)).c_str();
        if (subValue == 0)
        {
            str += " Unsubscribed to ";
        } else if (subValue == 1)
        {
            str += " Subscribed to notfications for ";
        } else if (subValue == 2)
        {
            str += " Subscribed to indications for ";
        } else if (subValue == 3)
        {
            str += " Subscribed to notifications and indications for ";
        }
        str += std::string(pCharacteristic->getUUID()).c_str();

        Serial.println(str);
    };
};

class DescriptorCallbacks : public NimBLEDescriptorCallbacks
{
    void onWrite(NimBLEDescriptor* pDescriptor)
    {
        std::string dscVal((char*) pDescriptor->getValue(), pDescriptor->getLength());
        Serial.print("Descriptor witten value:");
        Serial.println(dscVal.c_str());
    };

    void onRead(NimBLEDescriptor* pDescriptor)
    {
        Serial.print(pDescriptor->getUUID().toString().c_str());
        Serial.println(" Descriptor read");
    };
};

struct JointStatus_t
{
    NimBLEService* pService;
    NimBLECharacteristic* pChr_J1;
    NimBLECharacteristic* pChr_J2;
    NimBLECharacteristic* pChr_J3;
    NimBLECharacteristic* pChr_J4;
    NimBLECharacteristic* pChr_J5;
    NimBLECharacteristic* pChr_J6;
};

NimBLEServer* pServer;
DescriptorCallbacks dscCallbacks;
CharacteristicCallbacks chrCallbacks;

JointStatus_t jointStatus;
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

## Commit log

2021-05-19 [Hw] Add PCB project files.
    [ESP32-PicoDK.PrjPCB, Main.SchDoc]
2021-05-19 [Hw] Fixed missing key track.
    [ESP32-PicoDK.PrjPCB, Main.SchDoc]
2021-05-22 Add samples.
2021-05-22 Add gerber files.
    [ESP32-PicoDK.GBL, ESP32-PicoDK.GBO, ESP32-PicoDK.GBP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]
2021-05-23 Add IMU sample.
2021-05-25 Update PCB files.
    [ESP32-PicoDK.GBL, ESP32-PicoDK.GBO, ESP32-PicoDK.GBP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]
2021-05-26 Update README.
    [ESP32-PicoDK.PrjPCB, Main.SchDoc]
2021-05-26 Add Arduinio-IDE samples.
2021-05-26 Add case.
    [lower.step, upper.step]
2021-07-22 [Hw] Fixed MPU6050 FSYNC to GND problem.
    [ESP32-PicoDK.PrjPCB]
2021-09-23 Add BLE samples.
